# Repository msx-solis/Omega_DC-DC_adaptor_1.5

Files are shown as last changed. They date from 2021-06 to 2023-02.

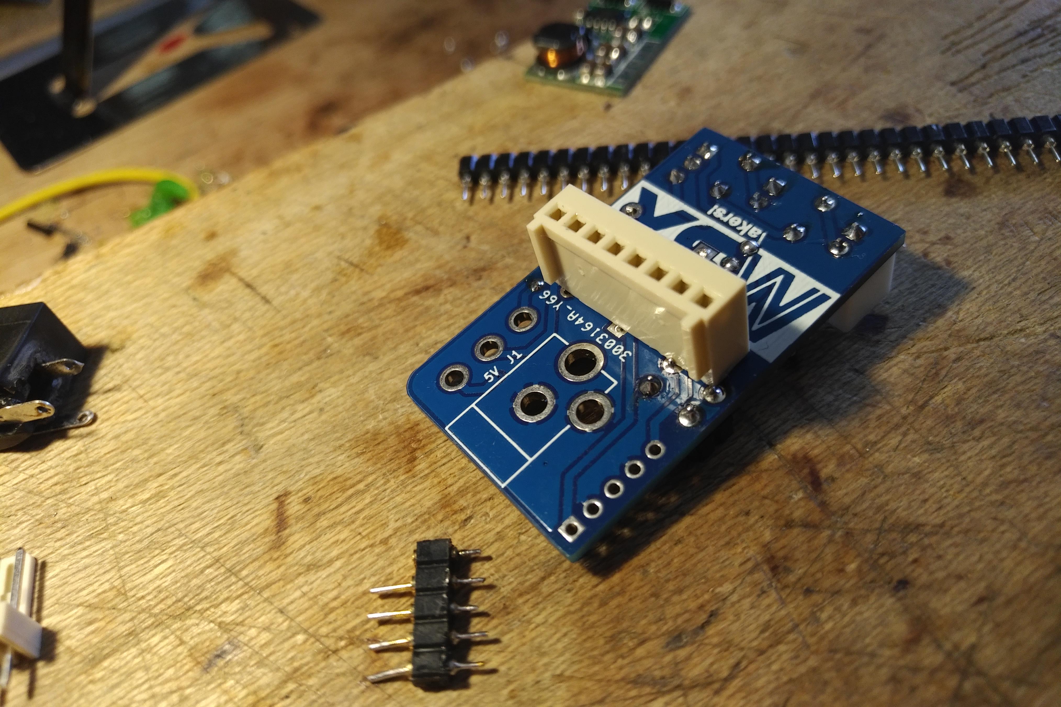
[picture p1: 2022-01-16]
pictures/IMG_20210710_1359004.jpg

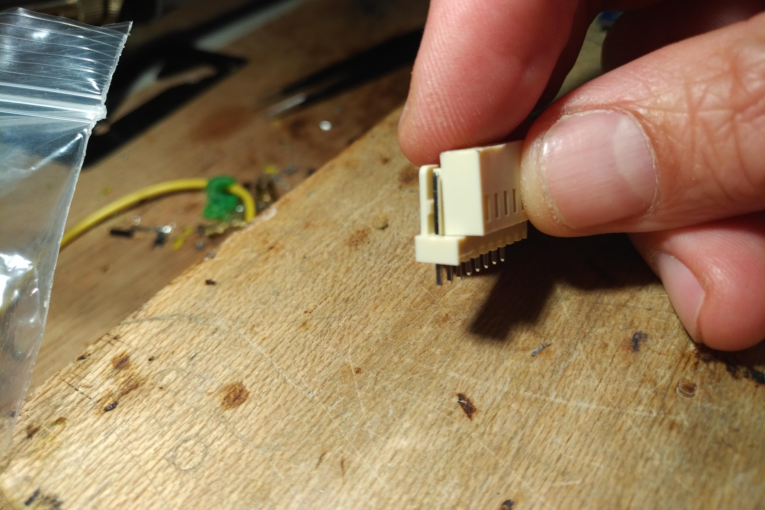
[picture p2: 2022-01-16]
pictures/IMG_20210710_0205476.jpg

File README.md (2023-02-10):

# Omega_DC-DC_adaptor
Actualización de la entrada de corriente para el OMEGA HOME COMPUTER

## v. 1.6
Mejorada la distribución de fusibles para independizar el fusible de cada canal 5v, anteriormente el fusible de la placa base y la unidad de discos era común, ahora hay un fusible independiente para ambas vias.

También se ha añadido una doble hilera de pines (J7 y J10) para permitir la conexión a la placa base con más de un tipo de conector (uno que conecta recto y otro que desplaza la conexión 2.54mm).

## v. 1.5
Este circuito mejora la seguridad y comodidad para la interconexión del circuito mini fuente DC-DC +12v -12v a la placa base del OMEGA HOME COMPUTER.
Permite la conexión de un interruptor de apagado, con una resistencia de descarga rapida, y también utilizar varios fusibles, uno por cada línea de tensión independiente.

Además incorpora varios enchufes independientes de alimnetación para conectar diversas ampliaciones internas en la carcasa, cada una unida a una conexión de fusible asociada.

La función que tienen el 1N4007 y el diodo zener es de protección, evitando daños en caso de una alimentación de polaridad inversa o de un voltaje algo superior.

Los valores de los fusibles rearmables son una sugerencia obtenida de las mediciones en mi equipo y con mis accesorios.

Hay varias versiones anteriores que no tenían fusibles ni conexión para interruptor.

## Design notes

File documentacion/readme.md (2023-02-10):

## documentación
En esta carpeta están los esquemas y representación 3d de las diferentes versiones, también el listado de materiales (BOM)

Las imágenes de la carpeta pictures són muy ilustrativas, a falta de un buen manual. Son de la versión 1.5.
Hay dos maneras de montar este circuito: (en realidad 3)
A) Con el conector DC soldado en la placa mini DC 1.5, cara abajo.
B) Con el conector soldado en la placa base pero el pin central doblado hacia arriba, insertado en la mini DC 1.5.
La primera opción permite desconectar el módulo rápidamente pero conviene soldar un conector robusto. 
El que muestro en algunas imagenes es un conector para cable adaptado.
La segunda opción requerirá utilizar el soldador para desconectar el modulo de la placa principal.

La tercera forma de montaje se explica en el blog. Es una alternativa en la que el interruptor está soldado directamente al la placa DC y no unido a la placa base (conectado pero mediante cable flexible).

En algunas imagenes soldé zócalos en lugar de los fusibles para poder hacer cambios fácilmente.

En la versión 1.6 añadí 2 zócalos de conexión de 8 pines para facilitar la conexión tanto de un conector robusto (desplazado) como de una tira de pines simple (vertical).

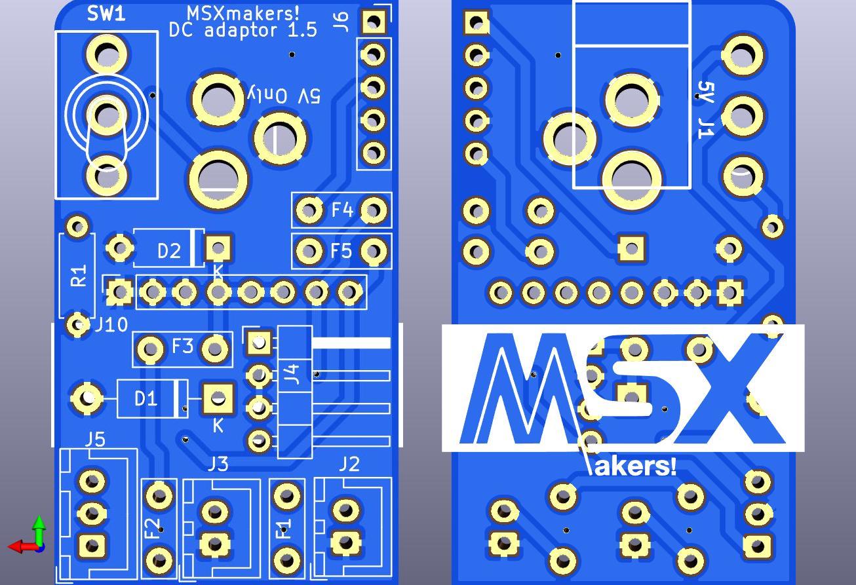
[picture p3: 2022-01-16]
pictures/Omega_DC-DC_adaptor.jpg

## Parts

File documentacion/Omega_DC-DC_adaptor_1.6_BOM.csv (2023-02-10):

Reference | Value | Footprint | Datasheet
J10 | OMEGA POWER SUPPLY | Connector_PinSocket_2.54mm:PinSocket_1x08_P2.54mm_Vertical
J1 | 5V | My_Components:Conn_Power_Jack_Circular_Pads
F3 | 1,5A | Capacitor_THT:C_Disc_D7.5mm_W2.5mm_P5.00mm | ~
R1 | 150 | Resistor_THT:R_Axial_DIN0207_L6.3mm_D2.5mm_P7.62mm_Horizontal | ~
D2 | 5.6V | Diode_THT:D_A-405_P7.62mm_Horizontal | ~
J2 | 5v audio | Connector_JST:JST_XH_B2B-XH-A_1x02_P2.50mm_Vertical | ~
J3 | 5v video | Connector_JST:JST_XH_B2B-XH-A_1x02_P2.50mm_Vertical | ~
J4 | floppy | Connector_PinHeader_2.54mm:PinHeader_1x04_P2.54mm_Horizontal | ~
F1 | 1,5A | Capacitor_THT:C_Disc_D7.5mm_W2.5mm_P5.00mm | ~
F2 | 1,5A | Capacitor_THT:C_Disc_D7.5mm_W2.5mm_P5.00mm | ~
J5 | FMPAC POWER SUPPLY | Connector_JST:JST_XH_B3B-XH-A_1x03_P2.50mm_Vertical | ~
J6 | POWER | Connector_PinSocket_2.54mm:PinSocket_1x05_P2.54mm_Vertical
F5 | 100mA | Capacitor_THT:C_Disc_D7.5mm_W2.5mm_P5.00mm | ~
F4 | 100mA | Capacitor_THT:C_Disc_D7.5mm_W2.5mm_P5.00mm | ~
D1 | 1N4007 | Diode_THT:D_DO-41_SOD81_P10.16mm_Horizontal | http://www.vishay.com/docs/88503/1n4001.pdf
SW1 | POWER SWITCH | MSXMakers:SWITCH_SPDT | ~
F6 | 1,5A | Capacitor_THT:C_Disc_D7.5mm_W2.5mm_P5.00mm | ~

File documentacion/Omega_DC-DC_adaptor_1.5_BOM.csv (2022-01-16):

Reference | qty | Value | link
D1 | 1 | 1N4007 | https://es.aliexpress.com/item/1005001456610390.html
D2 | 1 | 5.6V Zener | https://es.rs-online.com/web/p/products/5443604/
F1 | 1 | Fuse resettable 500mA (trigger 1A) | https://es.rs-online.com/web/p/products/5176635/
F2 | 1 | Fuse resettable 750mA (trigger 1,5A) | https://es.rs-online.com/web/p/products/5176663/
F3 | 1 | Fuse resettable 1,6A (trigger 3,2A) | https://es.rs-online.com/web/p/products/5176792/
F4, F5 | 2 | Fuse resettable 50mA (trigger 100mA) | https://es.rs-online.com/web/p/products/6478421/
J1 | 1 | DC Power Jack, 2,1mm | https://es.aliexpress.com/item/33005175186.html?spm=a2g0s.9042311.0.0.274263c0yTxl9o
J10 | 1 | 1x08 female pinheader | https://es.aliexpress.com/item/33011682095.html?spm=a2g0s.9042311.0.0.274263c0vVtfcn
J2, J3 | 2 | 2 pin male PCB JST vertical connector | https://es.aliexpress.com/item/32855763468.html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
J4 | 1 | 4 pin male connector. 2,54mm 90 degrees | https://es.aliexpress.com/item/33053313994.html
J5 | 1 | 3 pin male PCB JST vertical connector | https://es.aliexpress.com/item/32855763468.html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
J6 | 1 | 1x05 female straight pinheader | https://es.aliexpress.com/item/4000557204854.html?scm_id=1007.14976.197949.0&scm-url=1007.14976.197949.0&_t=g
no REF | 1 | SPDT ON-ON 6A switch | https://es.aliexpress.com/item/1005001667810183.html?spm=a2g0s.9042311.0.0.274263c00uYiCm
PCB | 1 | mini DC-DC 1.5 PCB adaptor with fuses | https://msxmakers.design.blog/2021/07/16/personaliza-tu-omega/#DC-1-5
R1 | 1 | 120 ohm 250mW | https://es.aliexpress.com/item/32952657927.html
SW1 | 1 | 3 way male terminal block | https://es.rs-online.com/web/p/products/8970730/

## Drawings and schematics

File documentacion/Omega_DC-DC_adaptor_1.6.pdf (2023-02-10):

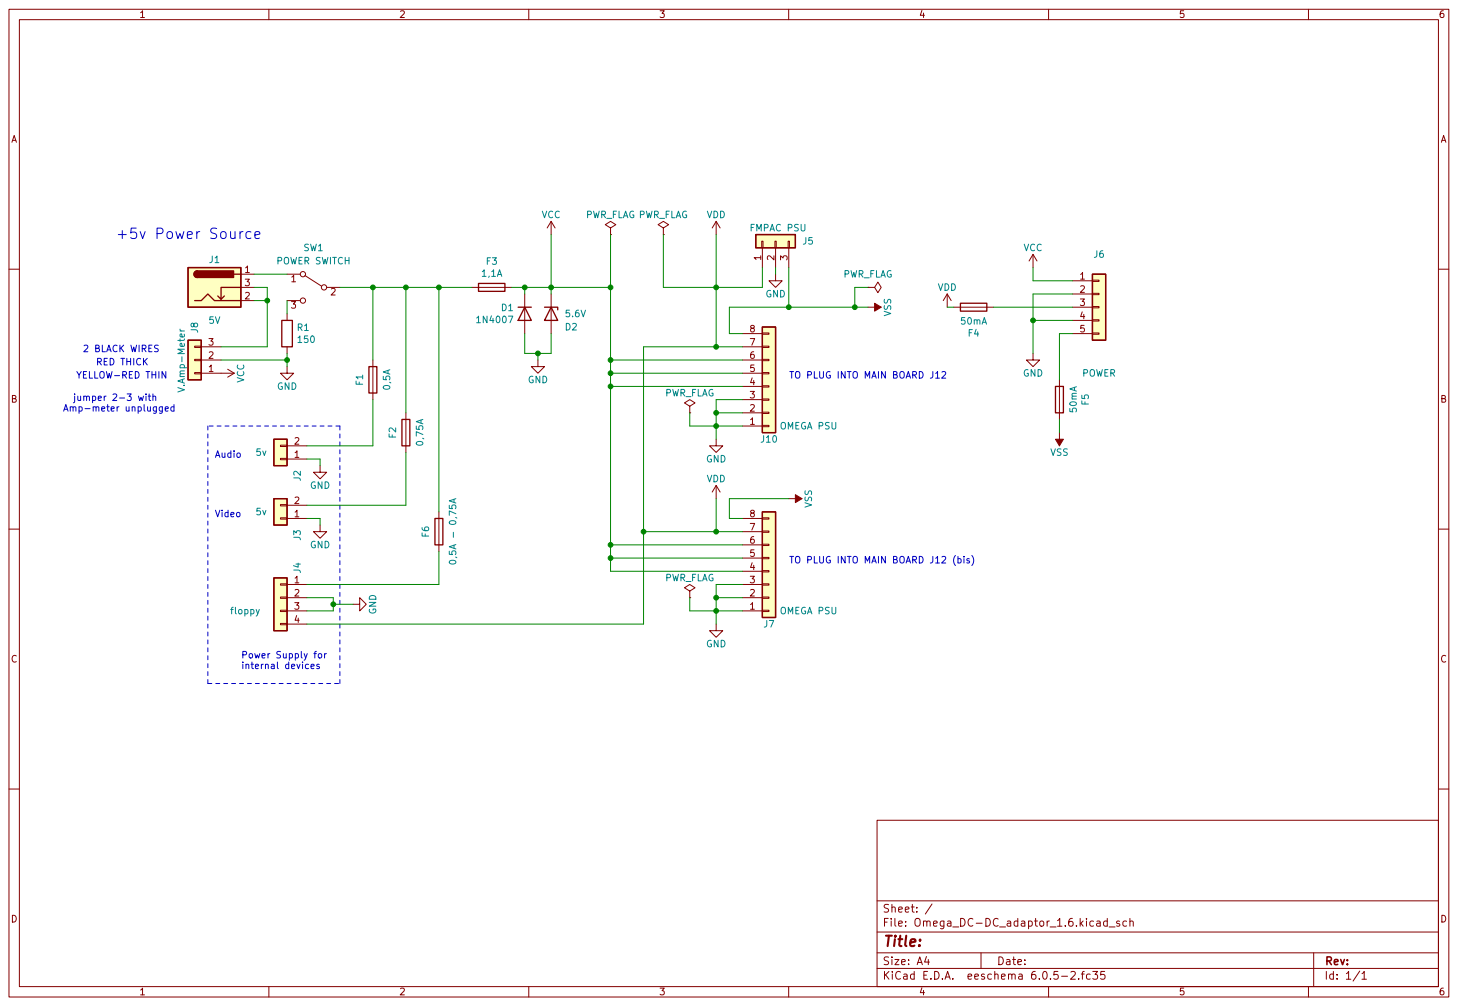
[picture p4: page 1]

2 BLACK WIRES
TO PLUG INTO MAIN BOARD J12 Audio RED THICK
YELLOW-RED THIN

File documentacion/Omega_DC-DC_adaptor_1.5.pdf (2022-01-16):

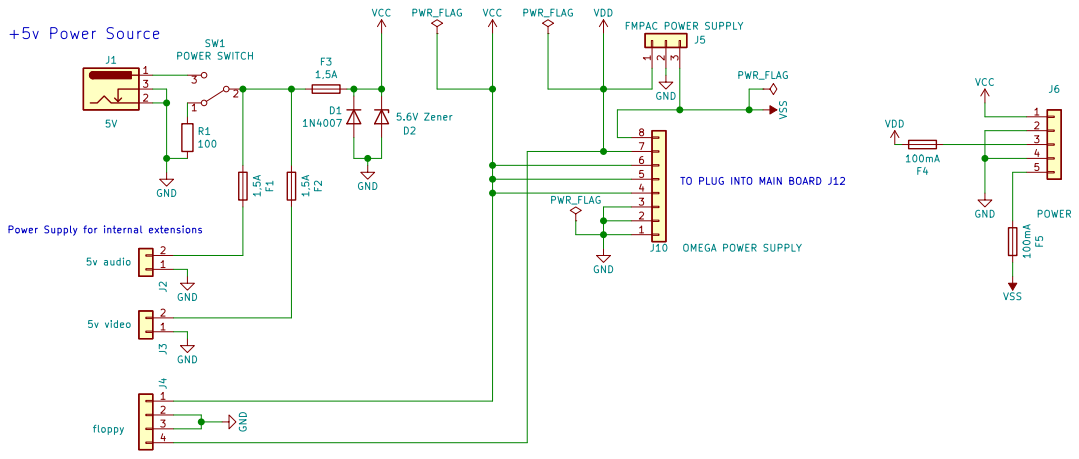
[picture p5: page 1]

TO PLUG INTO MAIN BOARD J12 Power Supply for internal extensions

PWR_FLAG 3

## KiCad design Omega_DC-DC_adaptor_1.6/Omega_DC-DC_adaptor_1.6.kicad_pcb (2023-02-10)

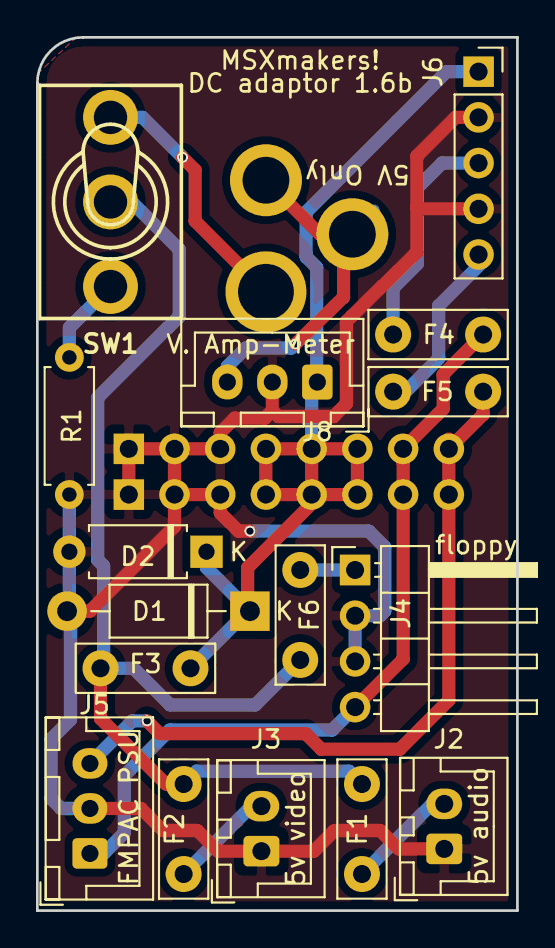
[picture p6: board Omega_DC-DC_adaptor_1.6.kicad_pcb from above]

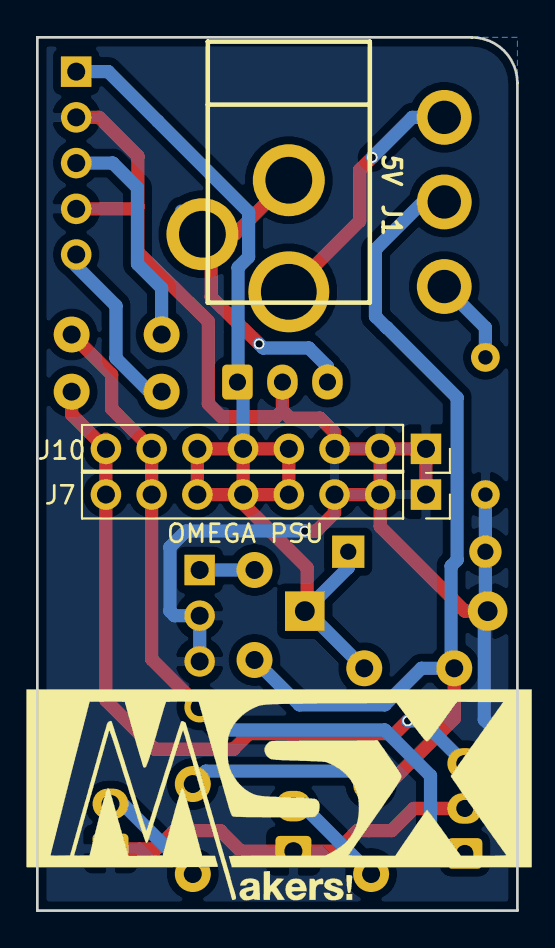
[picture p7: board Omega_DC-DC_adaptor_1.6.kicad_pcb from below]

Board: 2 copper layers, 26.7 x 48.5 mm, 19 parts (3 on the bottom side), 13 nets.

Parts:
D1: 1N4007; D_DO-41_SOD81_P10.16mm_Horizontal
D2: 5.6V; D_A-405_P7.62mm_Horizontal
F1, F2, F3, F6: 1,5A; C_Disc_D7.5mm_W2.5mm_P5.00mm
F4, F5: 100mA; C_Disc_D7.5mm_W2.5mm_P5.00mm
J1: 5V; Conn_Power_Jack_Circular_Pads
J2: 5v audio; JST_XH_B2B-XH-A_1x02_P2.50mm_Vertical
J3: 5v video; JST_XH_B2B-XH-A_1x02_P2.50mm_Vertical
J4: floppy; PinHeader_1x04_P2.54mm_Horizontal
J5: FMPAC PSU; JST_XH_B3B-XH-A_1x03_P2.50mm_Vertical
J6: POWER; PinSocket_1x05_P2.54mm_Vertical
J7: OMEGA POWER SUPPLY; PinSocket_1x08_P2.54mm_Vertical
J8: V. Amp-Meter; JST_XH_B3B-XH-A_1x03_P2.50mm_Vertical
J10: OMEGA PSU; PinSocket_1x08_P2.54mm_Vertical
R1: 150; R_Axial_DIN0207_L6.3mm_D2.5mm_P7.62mm_Horizontal
SW1: POWER SWITCH; SWITCH_SPDT

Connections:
GND: D1.2, D2.2, J2.1, J3.1, J4.2, J4.3, J5.2, J6.2, J6.4, J7.1, J7.2, J7.3, J8.2, J10.1, J10.2, J10.3, R1.2
unnamed: F1.1, J2.2
unnamed: F1.2, F2.2, F3.2, F6.2, SW1.2
unnamed: F2.1, J3.2
unnamed: F4.2, J6.3
unnamed: F5.2, J6.5
unnamed: F6.1, J4.1
unnamed: J1.1, SW1.1
unnamed: J1.2, J1.3, J8.3
unnamed: R1.1, SW1.3
VCC: D1.1, D2.1, F3.1, J6.1, J7.4, J7.5, J7.6, J8.1, J10.4, J10.5, J10.6
VDD: F4.1, J4.4, J5.1, J7.7, J10.7
VSS: F5.1, J5.3, J7.8, J10.8

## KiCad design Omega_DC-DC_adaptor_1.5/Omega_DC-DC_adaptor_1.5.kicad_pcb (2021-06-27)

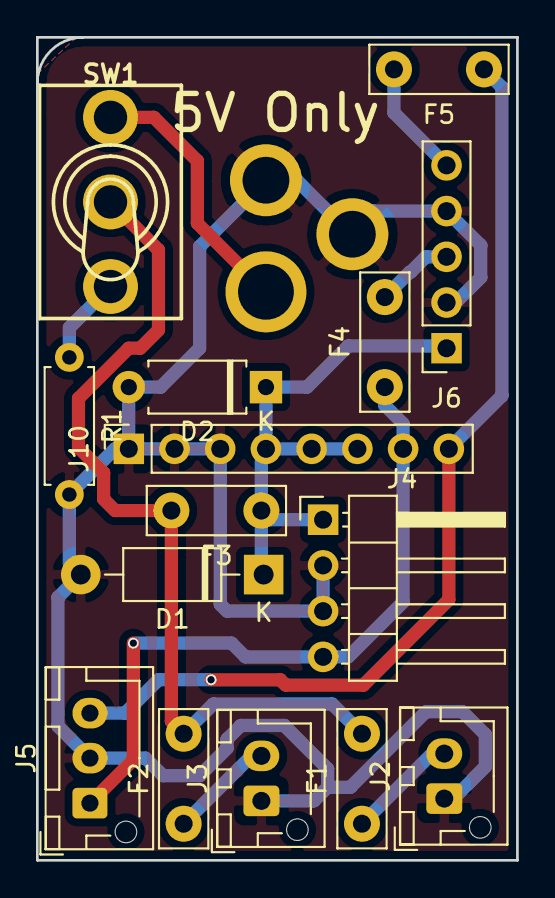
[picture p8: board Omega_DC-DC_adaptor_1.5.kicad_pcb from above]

Board: 2 copper layers, 26.7 x 45.7 mm, 16 parts (1 on the bottom side), 11 nets.

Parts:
D1: 1N4007; D_DO-41_SOD81_P10.16mm_Horizontal
D2: 5.6V; D_A-405_P7.62mm_Horizontal
F1, F2, F3: 1,5A; C_Disc_D7.5mm_W2.5mm_P5.00mm
F4, F5: 100mA; C_Disc_D7.5mm_W2.5mm_P5.00mm
J1: 5V; Conn_Power_Jack_Circular_Pads
J2: 5v audio; JST_XH_B2B-XH-AM_1x02_P2.50mm_Vertical
J3: 5v video; JST_XH_B2B-XH-AM_1x02_P2.50mm_Vertical
J4: floppy; PinHeader_1x04_P2.54mm_Horizontal
J5: FMPAC; JST_XH_B3B-XH-AM_1x03_P2.50mm_Vertical
J6: POWER; PinSocket_1x05_P2.54mm_Vertical
J10: POWER; PinSocket_1x08_P2.54mm_Vertical
R1: 100; R_Axial_DIN0207_L6.3mm_D2.5mm_P7.62mm_Horizontal
SW1: SW_SPDT; SWITCH_SPDT

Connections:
GND: D1.2, D2.2, J1.2, J1.3, J2.1, J3.1, J4.2, J4.3, J5.2, J6.2, J6.4, J10.1, J10.2, J10.3, R1.2
unnamed: F1.1, J2.2
unnamed: F1.2, F2.2, F3.2, SW1.2
unnamed: F2.1, J3.2
unnamed: F4.2, J6.3
unnamed: F5.2, J6.5
unnamed: J1.1, SW1.3
unnamed: R1.1, SW1.1
VCC: D1.1, D2.1, F3.1, J4.1, J6.1, J10.4, J10.5, J10.6
VDD: F4.1, J4.4, J5.1, J10.7
VSS: F5.1, J5.3, J10.8
